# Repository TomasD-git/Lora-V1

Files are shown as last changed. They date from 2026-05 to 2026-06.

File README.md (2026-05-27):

# Lora-V1
Very complicated Lora which is mainly for 868mhz but 966mhz would work as well, has a small cell battery to keep track of time for few years, with alot of controls and a screen





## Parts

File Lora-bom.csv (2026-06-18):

Name | Purpose | Quantity | Total Cost (USD) | Link | Distributor
Cap on rotary encoder | The cap on rotary encoders that makes it easier to rotate it | 1 | 2.30 | https://www.aliexpress.com/item/10000056483250.html | Aliexpress
rotary encoder | To type messages control everything | 1 | 3.87 | https://www.aliexpress.com/item/10000056483250.html?mp=1 | Aliexpress
Screen | Actual screen all messages are shown on | 1 | 3.94 | https://www.aliexpress.com/item/1005006862867338.html | Aliexpress
PCB + Stencil | Actual pcb which all components are on + Stencil | 1 | 44.45 | https://jlcpcb.com | JLCPCB
LCSC | all components needed for this project | 1 | 54.20 | https://lcsc.com | LCSC

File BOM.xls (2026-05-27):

JLCPCB BOM Tool - BOM Matching
BOM name：BOM-JLCPCB Assembly Order.xlsx |  |  | Download Time：2026-05-25 15:41:48 |  |  |  | * Our matching results are updated in real-time, but stock and prices may change. If it's been over 24 hours, please re-match before placing your order.
PCB Assembled Qty：5 |  |  | Est. Total Price：99.2277
Your BOM |  |  |  |  | Matched Parts |  |  |  |  |  |  | Order Information
Top Designator | Bottom Designator | Comment | Footprint | JLCPCB Part # | Matches | Part # | Manufacturer | Footprint | Description | Category | Warning | JLCPCB Part # | Product link | Lib Type | Qty | Source | Total Price ($)
C1 |  | 470nF | 0402 |  | Select by System | CL05B104KO5NNNC | Samsung Electro-Mechanics | 0402 | 100nF 16V X7R ±10% 0402 Multilayer Ceramic Capacitors MLCC - SMD/SMT ROHS | Multilayer Ceramic Capacitors MLCC - SMD/SMT |  | C1525 | https://jlcpcb.com/partdetail/1877-CL05B104KO5NNNC/C1525 | Basic | 20 | 20 JLCPCB | 0.03
C2 |  | 100uF | 1210 |  | Select by System | CL32A107MQVNNNE | Samsung Electro-Mechanics | 1210 | 100uF 6.3V X5R ±20% 1210 Multilayer Ceramic Capacitors MLCC - SMD/SMT ROHS | Multilayer Ceramic Capacitors MLCC - SMD/SMT |  | C49066 | https://jlcpcb.com/partdetail/50074-CL32A107MQVNNNE/C49066 | Extended | 7 | 7 JLCPCB | 1.3447
C5,C6 |  | 100pF | 0402 |  | Select by System | 0402CG101J500NT | FH (Guangdong Fenghua Advanced Tech) | 0402 | 100pF 50V C0G ±5% 0402 Multilayer Ceramic Capacitors MLCC - SMD/SMT ROHS | Multilayer Ceramic Capacitors MLCC - SMD/SMT |  | C1546 | https://jlcpcb.com/partdetail/1898-0402CG101J500NT/C1546 | Basic | 20 | 20 JLCPCB | 0.024
C10,C13,C4,C9 |  | 10pF | 0402 |  | Select by System | GRM1555C1H100GA01D | Murata Electronics | 0402 | 10pF 50V C0G ±2% 0402 Multilayer Ceramic Capacitors MLCC - SMD/SMT ROHS | Multilayer Ceramic Capacitors MLCC - SMD/SMT |  | C76945 | https://jlcpcb.com/partdetail/MurataElectronics-GRM1555C1H100GA01D/C76945 | Extended | 30 | 30 JLCPCB | 0.195
C11,C12,C7,C8 |  | 8.2pF | 0402 |  | Select by System | 0402CG8R2C500NT | FH (Guangdong Fenghua Advanced Tech) | 0402 | 50V 8.2pF C0G 0402 Multilayer Ceramic Capacitors MLCC - SMD/SMT ROHS | Multilayer Ceramic Capacitors MLCC - SMD/SMT |  | C1579 | https://jlcpcb.com/partdetail/1931-0402CG8R2C500NT/C1579 | Extended | 30 | 30 JLCPCB | 0.039
C14,C15 |  | 1nF | 0402 |  | Select by System | 0402CG102J500NT | FH (Guangdong Fenghua Advanced Tech) | 0402 | 1nF 50V C0G ±5% 0402 Multilayer Ceramic Capacitors MLCC - SMD/SMT ROHS | Multilayer Ceramic Capacitors MLCC - SMD/SMT |  | C53547 | https://jlcpcb.com/partdetail/54563-0402CG102J500NT/C53547 | Extended | 20 | 20 JLCPCB | 0.074
C16,C17,C18 |  | 33pF | 0402 |  | Select by System | 0402CG330J500NT | FH (Guangdong Fenghua Advanced Tech) | 0402 | 33pF 50V C0G ±5% 0402 Multilayer Ceramic Capacitors MLCC - SMD/SMT ROHS | Multilayer Ceramic Capacitors MLCC - SMD/SMT |  | C1562 | https://jlcpcb.com/partdetail/1914-0402CG330J500NT/C1562 | Basic | 25 | 25 JLCPCB | 0.0325
C19,C21,C3 |  | 1uF | 0402 |  | Select by System | CL05A105KA5NQNC | Samsung Electro-Mechanics | 0402 | 1uF 25V X5R ±10% 0402 Multilayer Ceramic Capacitors MLCC - SMD/SMT ROHS | Multilayer Ceramic Capacitors MLCC - SMD/SMT |  | C52923 | https://jlcpcb.com/partdetail/53938-CL05A105KA5NQNC/C52923 | Basic | 25 | 25 JLCPCB | 0.1
C20,C22,C23,C38 |  | 100nF | 0402 |  | Select by System | CL05B104KB54PNC | Samsung Electro-Mechanics | 0402 | 100nF 50V X7R ±10% 0402 Multilayer Ceramic Capacitors MLCC - SMD/SMT ROHS | Multilayer Ceramic Capacitors MLCC - SMD/SMT |  | C307331 | https://jlcpcb.com/partdetail/291005-CL05B104KB54PNC/C307331 | Basic | 30 | 30 JLCPCB | 0.138
C24 |  | 47nF | 0402 |  | Select by System | 0402B473K500NT | FH (Guangdong Fenghua Advanced Tech) | 0402 | 47nF 50V X7R ±10% 0402 Multilayer Ceramic Capacitors MLCC - SMD/SMT ROHS | Multilayer Ceramic Capacitors MLCC - SMD/SMT |  | C82219 | https://jlcpcb.com/partdetail/83376-0402B473K500NT/C82219 | Extended | 20 | 20 JLCPCB | 0.04
C25 |  | 4.7uF | 0603 |  | Select by System | CL10A475KO8NNNC | Samsung Electro-Mechanics | 0603 | 16V 4.7uF X5R ±10% 0603 Multilayer Ceramic Capacitors MLCC - SMD/SMT ROHS | Multilayer Ceramic Capacitors MLCC - SMD/SMT |  | C19666 | https://jlcpcb.com/partdetail/20375-CL10A475KO8NNNC/C19666 | Basic | 20 | 20 JLCPCB | 0.22
C26,C28,C29,C30,C31,C33 |  | 10uF | 0603 |  | Select by System | CL10A106KP8NNNC | Samsung Electro-Mechanics | 0603 | 10V 10uF X5R ±10% 0603 Multilayer Ceramic Capacitors MLCC - SMD/SMT ROHS | Multilayer Ceramic Capacitors MLCC - SMD/SMT |  | C19702 | https://jlcpcb.com/partdetail/20411-CL10A106KP8NNNC/C19702 | Basic | 40 | 40 JLCPCB | 0.428
C27,C32 |  | 22uF | 0805 |  | Select by System | CL21A226MAQNNNE | Samsung Electro-Mechanics | 0805 | 22uF 25V X5R ±20% 0805 Multilayer Ceramic Capacitors MLCC - SMD/SMT ROHS | Multilayer Ceramic Capacitors MLCC - SMD/SMT |  | C45783 | https://jlcpcb.com/partdetail/46786-CL21A226MAQNNNE/C45783 | Basic | 20 | 20 JLCPCB | 0.692
C34,C35,C36,C37 |  | 4.7nF | 0402 |  | Select by System | CC0402JRX7R9BB472 | YAGEO | 0402 | 4.7nF 50V X7R ±5% 0402 Multilayer Ceramic Capacitors MLCC - SMD/SMT ROHS | Multilayer Ceramic Capacitors MLCC - SMD/SMT |  | C281757 | https://jlcpcb.com/partdetail/YAGEO-CC0402JRX7R9BB472/C281757 | Extended | 30 | 30 JLCPCB | 0.054
CN1 |  | PH2.0 | 插件,P=2mm |  | Select by System | B2B-PH-K-S(LF)(SN) | JST | 插件,P=2mm | -25℃~+85℃ 1 100V 1x2P 2 2A 2P 2mm 4.5mm 5.9mm 6mm Brass K Pin PA66 PH Through Hole Tin UL94V-0 White 插件,P=2mm Wire To Board Connector ROHS | Wire To Board Connector |  | C131337 | https://jlcpcb.com/partdetail/JST-B2B_PH_K_S_LF_SN/C131337 | Extended | 6 | 6 JLCPCB | 0.1998
D1 |  | LED | 0603 |  | Select by System | XL-1608SURC-06 | XINGLIGHT | 0603 | -40℃~+85℃ 120° 2.3V 20mA 225mcd 50mW 620nm~630nm 625nm Discrete Diode Red Top-mount Water Clear 0603 LED Indication - Discrete ROHS | LED Indication - Discrete |  | C965799 | https://jlcpcb.com/partdetail/XINGLIGHT-XL_1608SURC06/C965799 | Extended | 20 | 20 JLCPCB | 0.076
J1 |  | Conn_Coaxial | SMD,D6.3xL5.4mm |  | Select by Customer | U.FL-R-SMT-1(80) | HRS(Hirose) | SMD | -40℃~+90℃ 1 1.25mm 2mm 50Ω 6GHz Board Side IPEX Male Pin SMD Coaxial Connectors (RF) ROHS | Coaxial Connectors (RF) |  | C88374 | https://jlcpcb.com/partdetail/HRS_Hirose-U_FL_R_SMT_1_80/C88374 | Extended | 7 | 7 JLCPCB | 0.7665
L1 |  | 15uH | 0805 |  | Select by System | MLZ2012M150WT000 | TDK | 0805 | 120mA 15uH 250mA 2MHz 950mΩ Multilayer inductor ±20% 0805 Inductors (SMD) ROHS | Inductors (SMD) |  | C383402 | https://jlcpcb.com/partdetail/TDK-MLZ2012M150WT000/C383402 | Extended | 9 | 9 JLCPCB | 0.5706
L2,L3,L4,L5,L6 |  | 8.2nH | 0402 |  | Select by System | LQW15AN8N2G00D | Murata Electronics | 0402 | 140mΩ 540mA 8.2nH Unshielded Inductor ±2% 0402 Power Inductors ROHS | Power Inductors |  | C84404 | https://jlcpcb.com/partdetail/MurataElectronics-LQW15AN8N2G00D/C84404 | Extended | 29 | 29 JLCPCB | 1.1716
L7 |  | 10nH | 0402 |  | Select by System | LQW15AN10NG00D | Murata Electronics | 0402 | 10nH 170mΩ 500mA Unshielded Inductor ±2% 0402 Power Inductors ROHS | Power Inductors |  | C90642 | https://jlcpcb.com/partdetail/MurataElectronics-LQW15AN10NG00D/C90642 | Extended | 9 | 9 JLCPCB | 0.3258
L8 |  | 2.2uH | 1008 |  | Select by System | LQM2HPN2R2MG0L | Murata Electronics | 1008 | 1.3A 100mΩ 2.2uH 40MHz ±20% 1008 Inductors (SMD) ROHS | Inductors (SMD) |  | C86092 | https://jlcpcb.com/partdetail/MurataElectronics-LQM2HPN2R2MG0L/C86092 | Extended | 7 | 7 JLCPCB | 0.6349
L9 |  | 1.5uH | 1210 |  | Select by System | NLV32T-1R5J-PF | TDK | 1210 | 1.5uH 370mA 850mΩ Magnetic Shielded Inductor ±5% 1210 Power Inductors ROHS | Power Inductors |  | C76837 | https://jlcpcb.com/partdetail/TDK-NLV32T_1R5JPF/C76837 | Extended | 9 | 9 JLCPCB | 0.4068
Q1,Q4 |  | 2N3904 | TO-92 |  | Select by System | 2N3904 | JSMSEMI | TO-92 | -55℃~+150℃ 1 NPN 200mA 300 300MHz 300mV 40V 50nA 625mW 6V NPN TO-92 Bipolar (BJT) ROHS | Bipolar (BJT) |  | C2874602 | https://jlcpcb.com/partdetail/JSMSEMI-2N3904/C2874602 | Extended | 12 | 12 JLCPCB | 0.144
Q2,Q3 |  | AO3401A | SOT-23 |  | Select by System | AO3401A | Alpha & Omega Semicon | SOT-23 | 1 P-Channel 14nC@10V 30V 47mΩ@10V、60mΩ@4.5V、85mΩ@2.5V 4A 55pF 645pF 80pF 900mV SOT-23 MOSFETs ROHS | MOSFETs |  | C15127 | https://jlcpcb.com/partdetail/Alpha_OmegaSemicon-AO3401A/C15127 | Basic | 14 | 14 JLCPCB | 0.8218
R1,R17 |  | 100K | 0402 |  | Select by System | FRC0402F1003TS | FOJAN | 0402 | -55℃~+155℃ 100kΩ 50V 62.5mW Thick Film Resistor ±1% ±100ppm/℃ 0402 Chip Resistor - Surface Mount ROHS | Chip Resistor - Surface Mount |  | C2906859 | https://jlcpcb.com/partdetail/FOJAN-FRC0402F1003TS/C2906859 | Extended | 20 | 20 JLCPCB | 0.012
R3,R4 |  | 22Ω | 0402 |  | Select by System | RC0402FR-0722RL | YAGEO | 0402 | -55℃~+155℃ 22Ω 50V 62.5mW Thick Film Resistor ±1% ±100ppm/℃ 0402 Chip Resistor - Surface Mount ROHS | Chip Resistor - Surface Mount |  | C114765 | https://jlcpcb.com/partdetail/YAGEO-RC0402FR0722RL/C114765 | Extended | 20 | 20 JLCPCB | 0.018
R6 |  | 15K | 0402 |  | Select by System | 0402WGF1502TCE | UNI-ROYAL(Uniroyal Elec) | 0402 | -55℃~+155℃ 15kΩ 50V 62.5mW Thick Film Resistor ±1% ±100ppm/℃ 0402 Chip Resistor - Surface Mount ROHS | Chip Resistor - Surface Mount |  | C25756 | https://jlcpcb.com/partdetail/26499-0402WGF1502TCE/C25756 | Basic | 20 | 20 JLCPCB | 0.016
R9 |  | 31.6K | 0402 |  | Select by System | RC0402FR-0731K6L | YAGEO | 0402 | -55℃~+155℃ 31.6kΩ 50V 62.5mW Thick Film Resistor ±1% ±100ppm/℃ 0402 Chip Resistor - Surface Mount ROHS | Chip Resistor - Surface Mount |  | C276265 | https://jlcpcb.com/partdetail/YAGEO-RC0402FR0731K6L/C276265 | Extended | 20 | 20 JLCPCB | 0.018
R10,R22,R24 |  | 1K | 0402 |  | Select by System | RC0402FR-071KL | YAGEO | 0402 | -55℃~+155℃ 1kΩ 50V 62.5mW Thick Film Resistor ±1% ±100ppm/℃ 0402 Chip Resistor - Surface Mount ROHS | Chip Resistor - Surface Mount |  | C106235 | https://jlcpcb.com/partdetail/YAGEO-RC0402FR071KL/C106235 | Extended | 25 | 25 JLCPCB | 0.0225
R11,R15,R18,R19,R2,R20,R21,R23,R25,R26,R27,R5,R7,R8 |  | 10K | 0402 |  | Select by System | FRC0402F1002TS | FOJAN | 0402 | -55℃~+155℃ 10kΩ 50V 62.5mW Thick Film Resistor ±1% ±100ppm/℃ 0402 Chip Resistor - Surface Mount ROHS | Chip Resistor - Surface Mount |  | C2906861 | https://jlcpcb.com/partdetail/FOJAN-FRC0402F1002TS/C2906861 | Extended | 80 | 80 JLCPCB | 0.048
R12,R13 |  | 5.1K | 0402 |  | Select by System | FRC0402F5101TS | FOJAN | 0402 | -55℃~+155℃ 5.1kΩ 50V 62.5mW Thick Film Resistor ±1% ±100ppm/℃ 0402 Chip Resistor - Surface Mount ROHS | Chip Resistor - Surface Mount |  | C2906874 | https://jlcpcb.com/partdetail/FOJAN-FRC0402F5101TS/C2906874 | Extended | 20 | 20 JLCPCB | 0.014
R14 |  | 178K | 0402 |  | Select by System | FRC0402F1783TS | FOJAN | 0402 | -55℃~+155℃ 178kΩ 50V 62.5mW Thick Film Resistor ±1% ±100ppm/℃ 0402 Chip Resistor - Surface Mount ROHS | Chip Resistor - Surface Mount |  | C3013156 | https://jlcpcb.com/partdetail/FOJAN-FRC0402F1783TS/C3013156 | Extended | 20 | 20 JLCPCB | 0.012
R16 |  | 267Ω | 0402 |  | Select by System | AC0402FR-07267RL | YAGEO | 0402 | -55℃~+155℃ 267Ω 50V 62.5mW Thick Film Resistor ±1% ±100ppm/℃ 0402 Chip Resistor - Surface Mount ROHS | Chip Resistor - Surface Mount |  | C226381 | https://jlcpcb.com/partdetail/YAGEO-AC0402FR07267RL/C226381 | Extended | 20 | 20 JLCPCB | 0.028
SW1 |  | RST | SMD-4P,6x6mm |  | Unconfirmed | PTS645SM43SMTR92LFS | C&K | SMD-4P,6x6mm | -20℃~+85℃ 1.6N 12V 4.3mm 50mA 6mm 6mm Gull Wing Round Button SPST Surface Mount,Vertical SMD-4P,6x6mm Tactile Switches ROHS | Tactile Switches | 1.Multiple lines in the BOM have been matched to the same part. Please check if the matching is correct. ; | C221880 | https://jlcpcb.com/partdetail/CK-PTS645SM43SMTR92LFS/C221880 | Extended | 15 | 15 JLCPCB | 4.0695
SW2 |  | BOOT | SMD-4P,6x6mm |  | Unconfirmed | PTS645SM43SMTR92LFS | C&K | SMD-4P,6x6mm | -20℃~+85℃ 1.6N 12V 4.3mm 50mA 6mm 6mm Gull Wing Round Button SPST Surface Mount,Vertical SMD-4P,6x6mm Tactile Switches ROHS | Tactile Switches | 1.Multiple lines in the BOM have been matched to the same part. Please check if the matching is correct. ; | C221880 | https://jlcpcb.com/partdetail/CK-PTS645SM43SMTR92LFS/C221880 | Extended | 15 | 15 JLCPCB | 4.0695
SW3 |  | PWR_RST | SMD-4P,6x6mm |  | Unconfirmed | PTS645SM43SMTR92LFS | C&K | SMD-4P,6x6mm | -20℃~+85℃ 1.6N 12V 4.3mm 50mA 6mm 6mm Gull Wing Round Button SPST Surface Mount,Vertical SMD-4P,6x6mm Tactile Switches ROHS | Tactile Switches | 1.Multiple lines in the BOM have been matched to the same part. Please check if the matching is correct. ; | C221880 | https://jlcpcb.com/partdetail/CK-PTS645SM43SMTR92LFS/C221880 | Extended | 15 | 15 JLCPCB | 4.0695
U1 |  | SX1262IMLTRT | QFN-24-EP(4x4) |  | Select by System | SX1262IMLTRT | SEMTECH | QFN-24-EP(4x4) | -148dBm -40℃~+85℃ 1.8V~3.7V 150MHz~960MHz 22dBm 300Kbps 32mA 4.2mA ISM SPI transceiver QFN-24-EP(4x4) RF Transceiver ICs ROHS | RF Transceiver ICs |  | C191341 | https://jlcpcb.com/partdetail/SEMTECH-SX1262IMLTRT/C191341 | Extended | 5 | 5 JLCPCB | 16.086
U2 |  | PE4259 | SC-70-6 |  | Select by System | PE4259-63 | pSemi | SC-70-6 | -40℃~+85℃ 0.35dB 1.8V~3.3V 10MHz~3GHz 30dB 33.5dBm Integrated control logic SPDT SC-70-6 RF Switches ROHS | RF Switches |  | C470892 | https://jlcpcb.com/partdetail/pSemi-PE425963/C470892 | Extended | 5 | 5 JLCPCB | 3.134
U3 |  | ESP32-S3-MINI-1U | VFQFN-56-EP |  | Select by System | ESP32-S3-MINI-1U-N8 | Espressif Systems | VFQFN-56-EP | -40℃~+105℃ -98.4dBm 1.8V~3.6V、3V~3.6V 2.4GHz 21dBm 340mA 88mA Bluetooth5.0 ESP32-S3 UART、SDIO、SPI、I2C、I2S、JTAG、USB VFQFN-56-EP WiFi Modules ROHS | WiFi Modules |  | C2980299 | https://jlcpcb.com/partdetail/3401551-ESP32_S3_MINI_1UN8/C2980299 | Extended | 5 | 5 JLCPCB | 24.9645
U4 |  | BQ25895RTW | QFN-24-EP(4x4) |  | Select by System | BQ25895RTWR | Texas Instruments | QFN-24-EP(4x4) | -40℃~+85℃ 1 12uA 3.9V~14V 4.608V 5A Charging IC I2C Lithium Battery Support Support QFN-24-EP(4x4) Battery Management ROHS | Battery Management |  | C80200 | https://jlcpcb.com/partdetail/TexasInstruments-BQ25895RTWR/C80200 | Extended | 5 | 5 JLCPCB | 11.0965
U5 |  | TPS631000DRLR | SOT-583 |  | Select by System | TPS631000DRLR | Texas Instruments | SOT-583 | -40℃~+125℃ 1.2V~5.3V 1.6V~5.5V 2.2MHz 2A 8uA Adjustable Buck-Boost Buck-Boost Built-in SOT-583 DC-DC Converters ROHS | DC-DC Converters |  | C5219190 | https://jlcpcb.com/partdetail/TexasInstruments-TPS631000DRLR/C5219190 | Extended | 5 | 5 JLCPCB | 2.3625
U6 |  | W25Q128JVPIMTR | WSON-8-EP(5x6) |  | Select by System | W25Q128JVPIM TR | Winbond Elec | WSON-8-EP(5x6) | -40℃~+85℃ 100,000 cycles 10uA 128Mbit 133MHz 2.7V~3.6V 20 Years 3ms SPI WSON-8-EP(5x6) NOR FLASH ROHS | NOR FLASH |  | C2441427 | https://jlcpcb.com/partdetail/WinbondElec-W25Q128JVPIMTR/C2441427 | Extended | 5 | 5 JLCPCB | 14.254
U7 |  | XDCR-1220-006 | SMD |  | Select by System | XDCR-1220-006 | Lian Xin Technology | SMD | -40℃~+85℃ Battery base CR1220 Gold SMD Button And Strip Battery Connector ROHS | Button And Strip Battery Connector |  | C7498147 | https://jlcpcb.com/partdetail/Lian_XinTechnology-XDCR_1220006/C7498147 | Extended | 5 | 5 JLCPCB | 0.724
U8 |  | PCF85063ATL/1,118 | DFN-10-EP(2.6x2.6) |  | Select by System | PCF85063ATL/1,118 | NXP Semicon | DFN-10-EP(2.6x2.6) | -40℃~+85℃ 0.22uA 220nA 900mV~5.5V Built-in I2C InsideSRAM/NVRAM、Programmable clock output、Alarm function、Periodic interrupt output、Countdown timer Yes DFN-10-EP(2.6x2.6) Real Time Clocks ROHS | Real Time Clocks |  | C404360 | https://jlcpcb.com/partdetail/NXPSemicon-PCF85063ATL_1118/C404360 | Extended | 5 | 5 JLCPCB | 3.7445
USB1 |  | USB-TYPE-C-018 | SMD |  | Select by System | USB-TYPE-C-018 | DEALON | SMD | -25℃~+85℃ 1 10000 times 16P 3A 5V 7.35mm Female Surface Mount, Right Angle Type-C SMD USB Connectors ROHS | USB Connectors |  | C2927038 | https://jlcpcb.com/partdetail/DEALON-USB_TYPE_C018/C2927038 | Extended | 5 | 5 JLCPCB | 0.2805
Y1 |  | 32MHz | SMD3225-4P |  | Select by System | X322532MMB4SI | YXC Crystal Oscillators | SMD3225-4P | -40℃~+85℃ 10pF 32MHz Crystal Oscillator ±10ppm ±20ppm SMD3225-4P Crystals ROHS | Crystals |  | C113671 | https://jlcpcb.com/partdetail/114906-X322532MMB4SI/C113671 | Extended | 9 | 9 JLCPCB | 0.7452
Y3 |  | 32.768kHz | SMD3215-2P |  | Select by System | Q13FC13500002 | Seiko Epson | SMD3215-2P | -40℃~+85℃ 32.768kHz 70kΩ 7pF Crystal Oscillator ±20ppm SMD3215-2P Crystals ROHS | Crystals |  | C48615 | https://jlcpcb.com/partdetail/SeikoEpson-Q13FC13500002/C48615 | Extended | 5 | 5 JLCPCB | 0.91

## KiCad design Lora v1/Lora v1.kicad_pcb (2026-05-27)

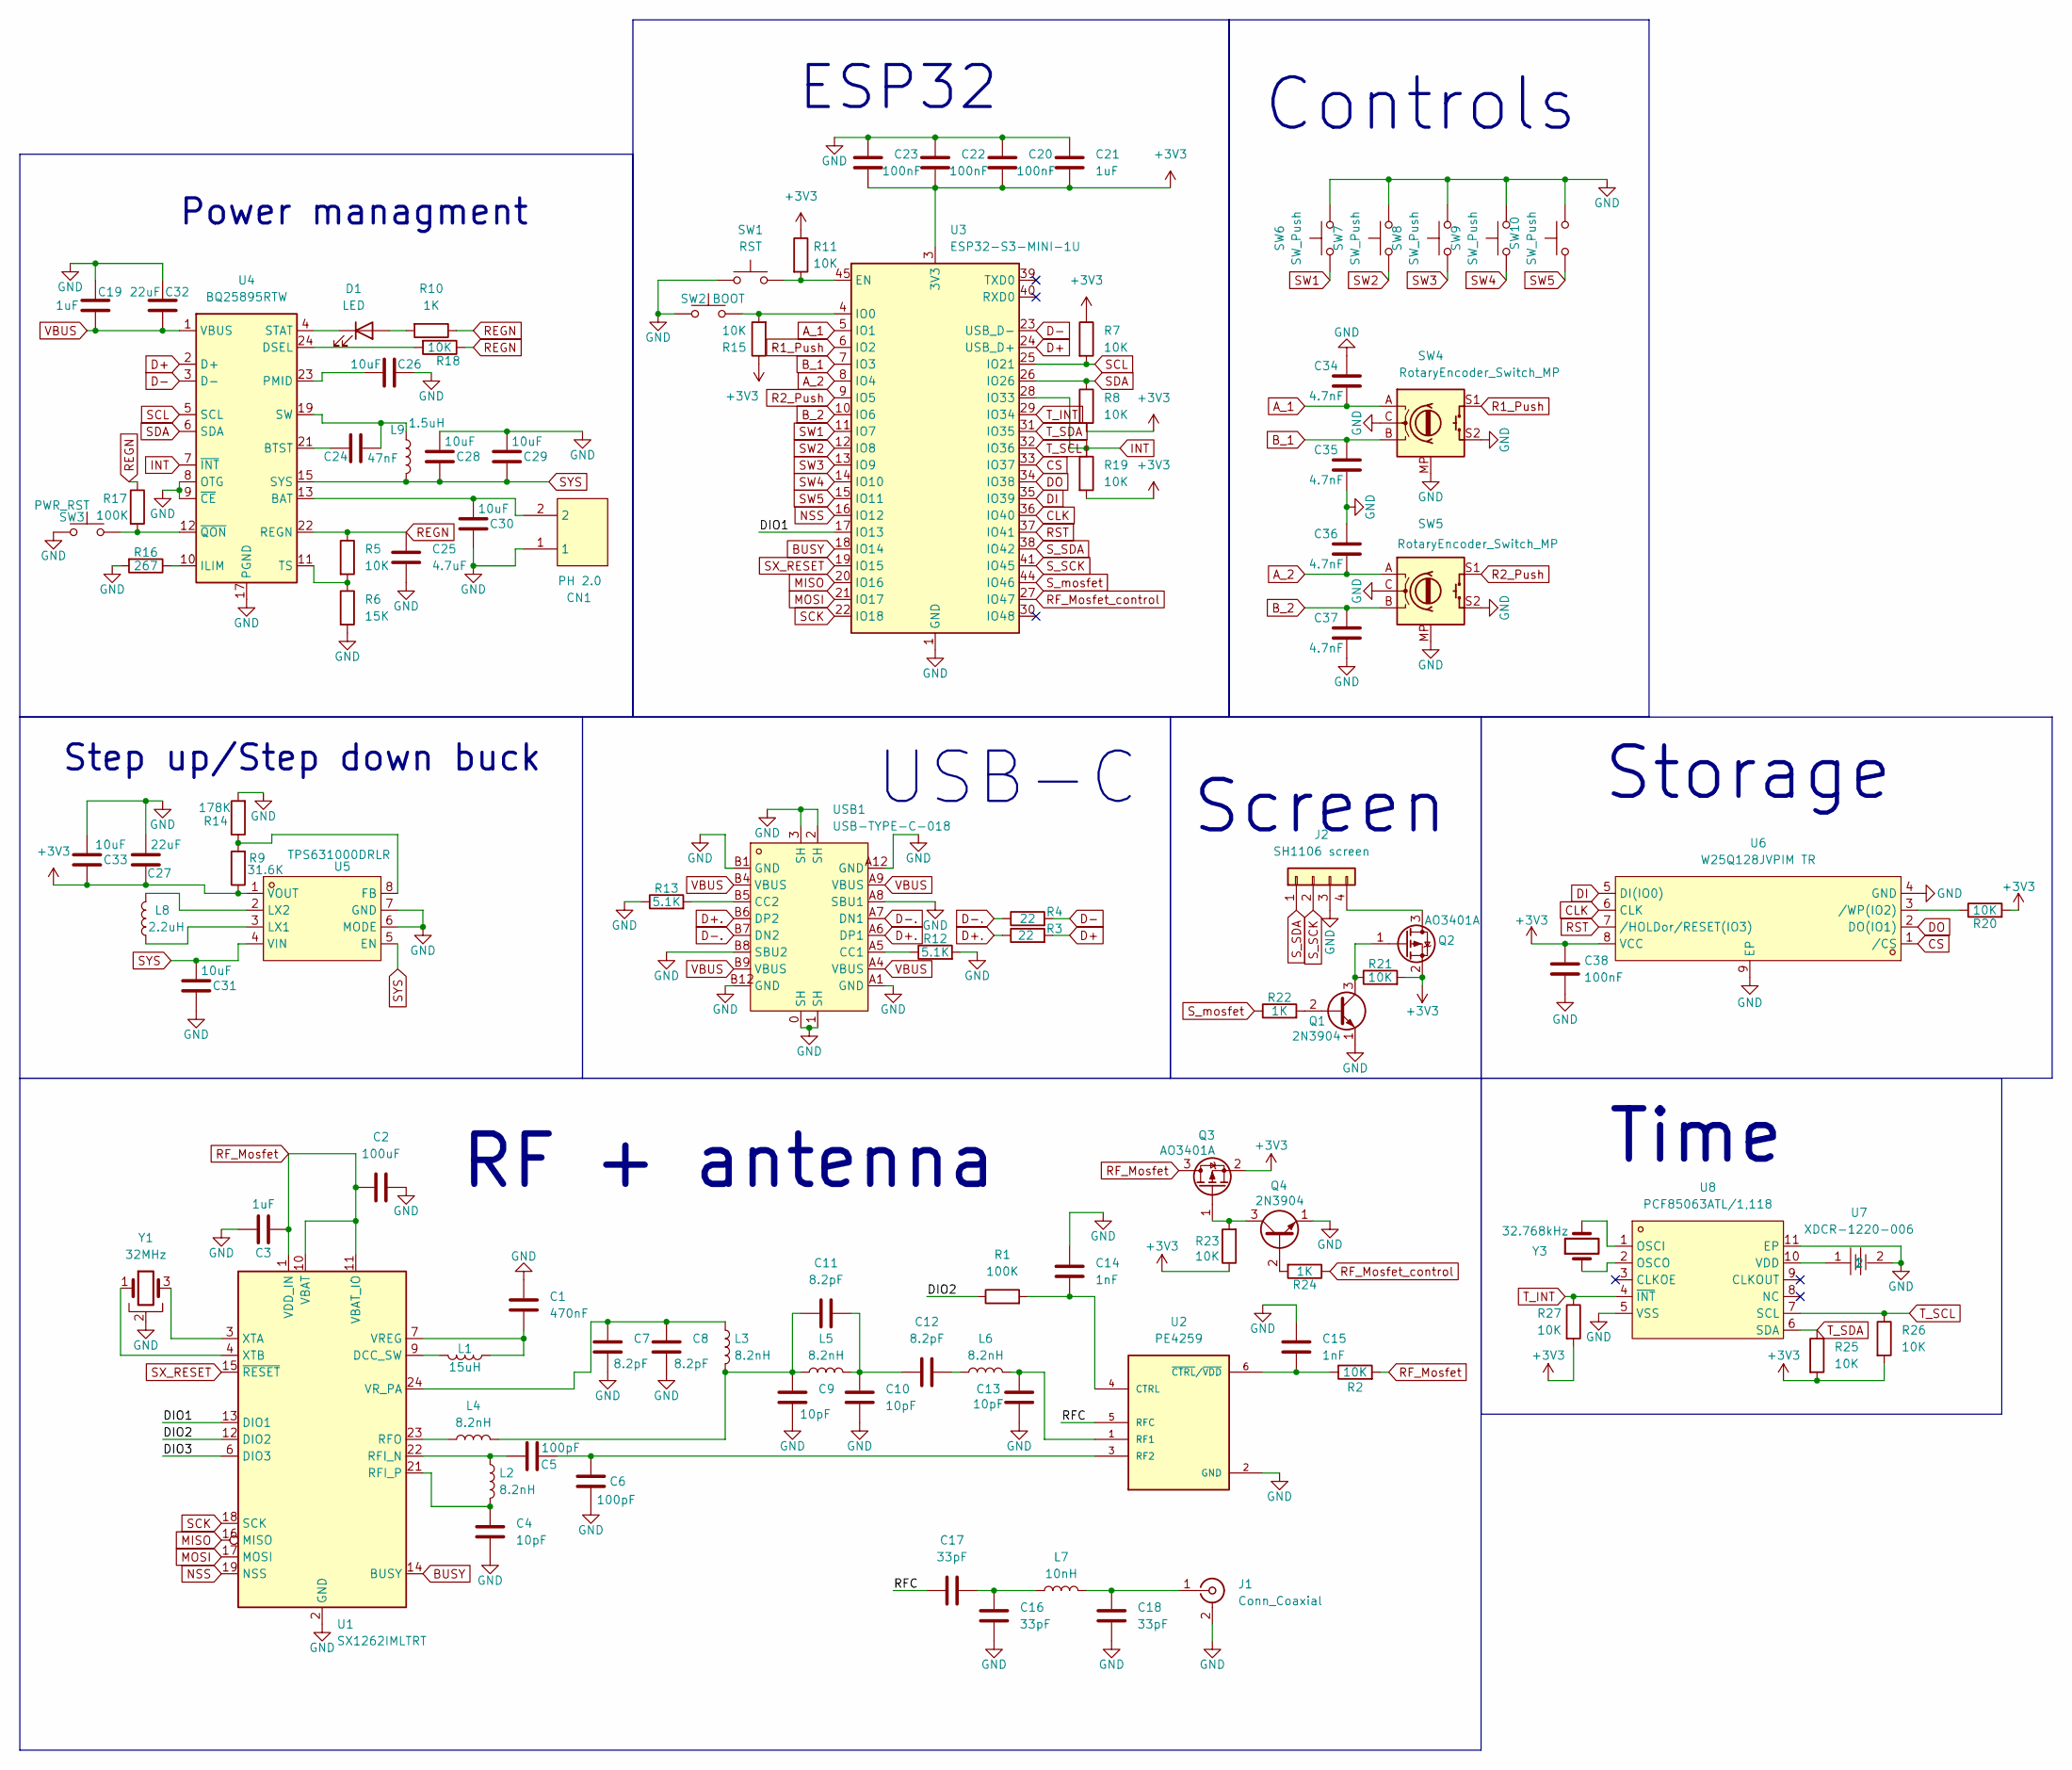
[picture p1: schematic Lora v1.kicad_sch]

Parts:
C1: 470nF; C_0402_1005Metric
C2: 100uF; C_1210_3225Metric
C3, C19, C21: 1uF; C_0402_1005Metric
C4, C9, C10, C13: 10pF; C_0402_1005Metric
C5, C6: 100pF; C_0402_1005Metric
C7, C8, C11, C12: 8.2pF; C_0402_1005Metric
C14, C15: 1nF; C_0402_1005Metric
C16, C17, C18: 33pF; C_0402_1005Metric
C20, C22, C23, C38: 100nF; C_0402_1005Metric
C24: 47nF; C_0402_1005Metric
C25: 4.7uF; C_0603_1608Metric
C26, C28, C29, C30, C31, C33: 10uF; C_0603_1608Metric
C27, C32: 22uF; C_0805_2012Metric
C34, C35, C36, C37: 4.7nF; C_0402_1005Metric
CN1: PH 2.0; CONN-TH_B2B-PH-K-S; MPN B2B-PH-K-S(LF)(SN); LCSC Part C131337
D1: LED; LED_0603_1608Metric
J1: Conn_Coaxial; U.FL_Hirose_U.FL-R-SMT-1_Vertical
J2: SH1106 screen; PinHeader_1x04_P2.54mm_Vertical
L1: 15uH; L_0805_2012Metric
L2, L3, L4, L5, L6: 8.2nH; L_0402_1005Metric
L7: 10nH; L_0402_1005Metric
L8: 2.2uH; L_1008_2520Metric
L9: 1.5uH; L_1210_3225Metric
Q1, Q4: 2N3904; TO-92_Inline
Q2, Q3: AO3401A; SOT-23
R1, R17: 100K; R_0402_1005Metric
R2, R5, R7, R8, R11, R15, R18, R19, R20, R21, R23, R25, R26, R27: 10K; R_0402_1005Metric
R3, R4: 22; R_0402_1005Metric
R6: 15K; R_0402_1005Metric
R9: 31.6K; R_0402_1005Metric
R10, R22, R24: 1K; R_0402_1005Metric
R12, R13: 5.1K; R_0402_1005Metric
R14: 178K; R_0402_1005Metric
R16: 267; R_0402_1005Metric
SW1: RST; SW_SPST_PTS645Sx43SMTR92
SW2: BOOT; SW_SPST_PTS645Sx43SMTR92
SW3: PWR_RST; SW_SPST_PTS645Sx43SMTR92
SW4, SW5: RotaryEncoder_Switch_MP; RotaryEncoder_Alps_EC11E-Switch_Vertical_H20mm
SW6, SW7, SW8, SW9, SW10: SW_Push; SW_Cherry_MX_PCB_1.00u
U1: SX1262IMLTRT; QFN-24-1EP_4x4mm_P0.5mm_EP2.6x2.6mm
U2: PE4259; SOT65P215X110-6N
U3: ESP32-S3-MINI-1U; ESP32-S2-MINI-1U
U4: BQ25895RTW; Texas_RTW_WQFN-24-1EP_4x4mm_P0.5mm_EP2.7x2.7mm_ThermalVias
U5: TPS631000DRLR; SOT-583-8_L2.1-W1.2-P0.50-LS1.6-BL; MPN TPS631000DRLR; LCSC Part C5219190
U6: W25Q128JVPIM TR; WSON-8_L6.0-W5.0-P1.27-BL-EP; MPN W25Q128JVPIM TR; LCSC Part C2441427
U7: XDCR-1220-006; BAT-SMD_CR1220-2ZX; MPN XDCR-1220-006; LCSC Part C7498147
U8: PCF85063ATL/1,118; DFN-10_L2.6-W2.6-P0.50-BL-EP; MPN PCF85063ATL/1,118; LCSC Part C404360
USB1: USB-TYPE-C-018; USB-C_SMD-TYPE-C-31-M-12; MPN USB-TYPE-C-018; LCSC Part C2927038
Y1: 32MHz; Crystal_SMD_3225-4Pin_3.2x2.5mm
Y3: 32.768kHz; Crystal_SMD_3215-2Pin_3.2x1.5mm

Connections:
+3V3: C20.2, C21.2, C22.2, C23.2, C27.1, C33.1, C38.1, Q2.2 (S), Q3.2 (S), R7.1, R8.2, R9.1, R11.1, R15.1, R19.2, R20.2, R21.2, R23.1, R25.2, R26.2, R27.2, U3.3 (3V3), U5.1 (VOUT), U6.8 (VCC)
/DIO1: U1.13 (DIO1), U3.17 (IO13)
/DIO2: R1.1, U1.12 (DIO2)
/DIO3: U1.6 (DIO3)
/RFC: C17.1, U2.5 (RFC)
A_1: C34.1, SW4.A, U3.5 (IO1)
A_2: C36.1, SW5.A, U3.8 (IO4)
BUSY: U1.14 (BUSY), U3.18 (IO14)
B_1: C35.2, SW4.B, U3.7 (IO3)
B_2: C37.2, SW5.B, U3.10 (IO6)
CLK: U3.36 (IO40), U6.6 (CLK)
CS: U3.33 (IO37), U6.1 (/CS)
D+: R3.2, U3.24 (USB_D+), U4.2 (D+)
D+.: R3.1, USB1.A6 (DP1), USB1.B6 (DP2)
D-: R4.2, U3.23 (USB_D-), U4.3 (D-)
D-.: R4.1, USB1.A7 (DN1), USB1.B7 (DN2)
DI: U3.35 (IO39), U6.5 (DI(IO0))
DO: U3.34 (IO38), U6.2 (DO(IO1))
GND: C1.1, C2.2, C3.1, C4.2, C6.1, C7.2, C8.2, C9.2, C10.2, C13.2, C14.1, C15.1, C16.2, C18.2, C19.1, C20.1, C21.1, C22.1, C23.1, C25.2, C26.2, C27.2, C28.2, C29.2, C30.1, C31.1, C32.1, C33.2, C34.2, C35.1, C36.2, C37.1, C38.2, CN1.1, J1.2 (Ext), J2.3, Q1.1 (E), Q4.1 (E), R6.2, R12.2, R13.1, R14.2, R16.2, SW1.1, SW2.1, SW3.1, SW4.C, SW4.MP, SW4.S2, SW5.C, SW5.MP, SW5.S2, SW6.2, SW7.2, SW8.2, SW9.2, SW10.2, U1.2 (GND), U1.5 (GND), U1.8 (GND), U1.20 (GND), U1.25 (GND), U2.2 (GND), U3.1 (GND), U3.2 (GND), U3.42 (GND), U3.43 (GND), U3.46 (GND), U3.47 (GND), U3.48 (GND), U3.49 (GND), U3.50 (GND), U3.51 (GND), U3.52 (GND), U3.53 (GND), U3.54 (GND), U3.55 (GND), U3.56 (GND), U3.57 (GND), U3.58 (GND), U3.59 (GND), U3.60 (GND), U3.61 (GND), U3.62 (GND), U3.63 (GND), U3.64 (GND), U3.65 (GND), U4.8 (OTG), U4.9 (~CE), U4.17 (PGND), U4.18 (PGND), U4.25 (PGND), U5.6 (MODE), U5.7 (GND), U6.4 (GND), U6.9 (EP), U7.2, U8.5 (VSS), U8.11 (EP), USB1.0 (SH), USB1.1 (SH), USB1.2 (SH), USB1.3 (SH), USB1.A1 (GND), USB1.A8 (SBU1), USB1.A12 (GND), USB1.B1 (GND), USB1.B8 (SBU2), USB1.B12 (GND), Y1.2
INT: R19.1, U3.28 (IO33), U4.7 (~INT)
MISO: U1.16 (MISO), U3.20 (IO16)
MOSI: U1.17 (MOSI), U3.21 (IO17)
NSS: U1.19 (NSS), U3.16 (IO12)
unnamed: C10.1, C11.2, C12.1, L5.2
unnamed: C9.1, C11.1, L3.2, L4.2, L5.1
unnamed: C12.2, L6.1
unnamed: C16.1, C17.2, L7.1
unnamed: C24.1, L9.1, U4.19 (SW), U4.20 (SW)
unnamed: C30.2, CN1.2, U4.13 (BAT), U4.14 (BAT)
unnamed: D1.2 (A), R10.2
unnamed: D1.1 (K), U4.4 (STAT)
unnamed: C18.1, J1.1 (In), L7.2
unnamed: J2.4, Q2.3 (D)
unnamed: Q1.2 (B), R22.2
unnamed: Q1.3 (C), Q2.1 (G), R21.1
unnamed: Q3.1 (G), Q4.3 (C), R23.2
unnamed: Q4.2 (B), R24.2
unnamed: L1.2, U1.9 (DCC_SW)
unnamed: C5.1, L2.1, U1.22 (RFI_N)
unnamed: C4.1, L2.2, U1.21 (RFI_P)
unnamed: L4.1, U1.23 (RFO)
unnamed: C1.2, L1.1, U1.7 (VREG)
unnamed: C7.1, C8.1, L3.1, U1.24 (VR_PA)
unnamed: U1.3 (XTA), Y1.3
unnamed: U1.4 (XTB), Y1.1
unnamed: C14.2, R1.2, U2.4 (CTRL)
unnamed: C13.1, L6.2, U2.1 (RF1)
unnamed: C5.2, C6.2, U2.3 (RF2)
unnamed: C15.2, R2.1, U2.6 (~CTRL/~VDD)
unnamed: R11.2, SW1.2, U3.45 (EN)
unnamed: R15.2, SW2.2, U3.4 (IO0)
unnamed: C24.2, U4.21 (BTST)
unnamed: R18.2, U4.24 (DSEL)
unnamed: R16.1, U4.10 (ILIM)
unnamed: C26.1, U4.23 (PMID)
unnamed: R5.2, R6.1, U4.11 (TS)
unnamed: R17.2, SW3.2, U4.12 (~QON)
unnamed: R9.2, R14.1, U5.8 (FB)
unnamed: L8.1, U5.3 (LX1)
unnamed: L8.2, U5.2 (LX2)
unnamed: R20.1, U6.3 (/WP(IO2))
unnamed: U8.1 (OSCI), Y3.2
unnamed: U8.2 (OSCO), Y3.1
unnamed: U7.1, U8.10 (VDD)
unnamed: R12.1, USB1.A5 (CC1)
unnamed: R13.2, USB1.B5 (CC2)
R1_Push: SW4.S1, U3.6 (IO2)
R2_Push: SW5.S1, U3.9 (IO5)
REGN: C25.1, R5.1, R10.1, R17.1, R18.1, U4.22 (REGN)
RF_Mosfet: C2.1, C3.2, Q3.3 (D), R2.2, U1.1 (VDD_IN), U1.10 (VBAT), U1.11 (VBAT_IO)
RF_Mosfet_control: R24.1, U3.27 (IO47)
RST: U3.37 (IO41), U6.7 (/HOLDor/RESET(IO3))
SCK: U1.18 (SCK), U3.22 (IO18)
SCL: R7.2, U3.25 (IO21), U4.5 (SCL)
SDA: R8.1, U3.26 (IO26), U4.6 (SDA)
SW1: SW6.1, U3.11 (IO7)
SW2: SW7.1, U3.12 (IO8)
SW3: SW8.1, U3.13 (IO9)
SW4: SW9.1, U3.14 (IO10)
SW5: SW10.1, U3.15 (IO11)
SX_RESET: U1.15 (~RESET), U3.19 (IO15)
SYS: C28.1, C29.1, C31.2, L9.2, U4.15 (SYS), U4.16 (SYS), U5.4 (VIN), U5.5 (EN)
S_SCK: J2.2, U3.41 (IO45)
S_SDA: J2.1, U3.38 (IO42)
S_mosfet: R22.1, U3.44 (IO46)
T_INT: R27.1, U3.29 (IO34), U8.4 (~INT)
T_SCL: R26.1, U3.32 (IO36), U8.7 (SCL)
T_SDA: R25.1, U3.31 (IO35), U8.6 (SDA)
VBUS: C19.2, C32.2, U4.1 (VBUS), USB1.A4 (VBUS), USB1.A9 (VBUS), USB1.B4 (VBUS), USB1.B9 (VBUS)

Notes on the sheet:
Power managment
Step up/Step down buck
Time
Storage
Controls
ESP32
RF + antenna
USB-C
Screen

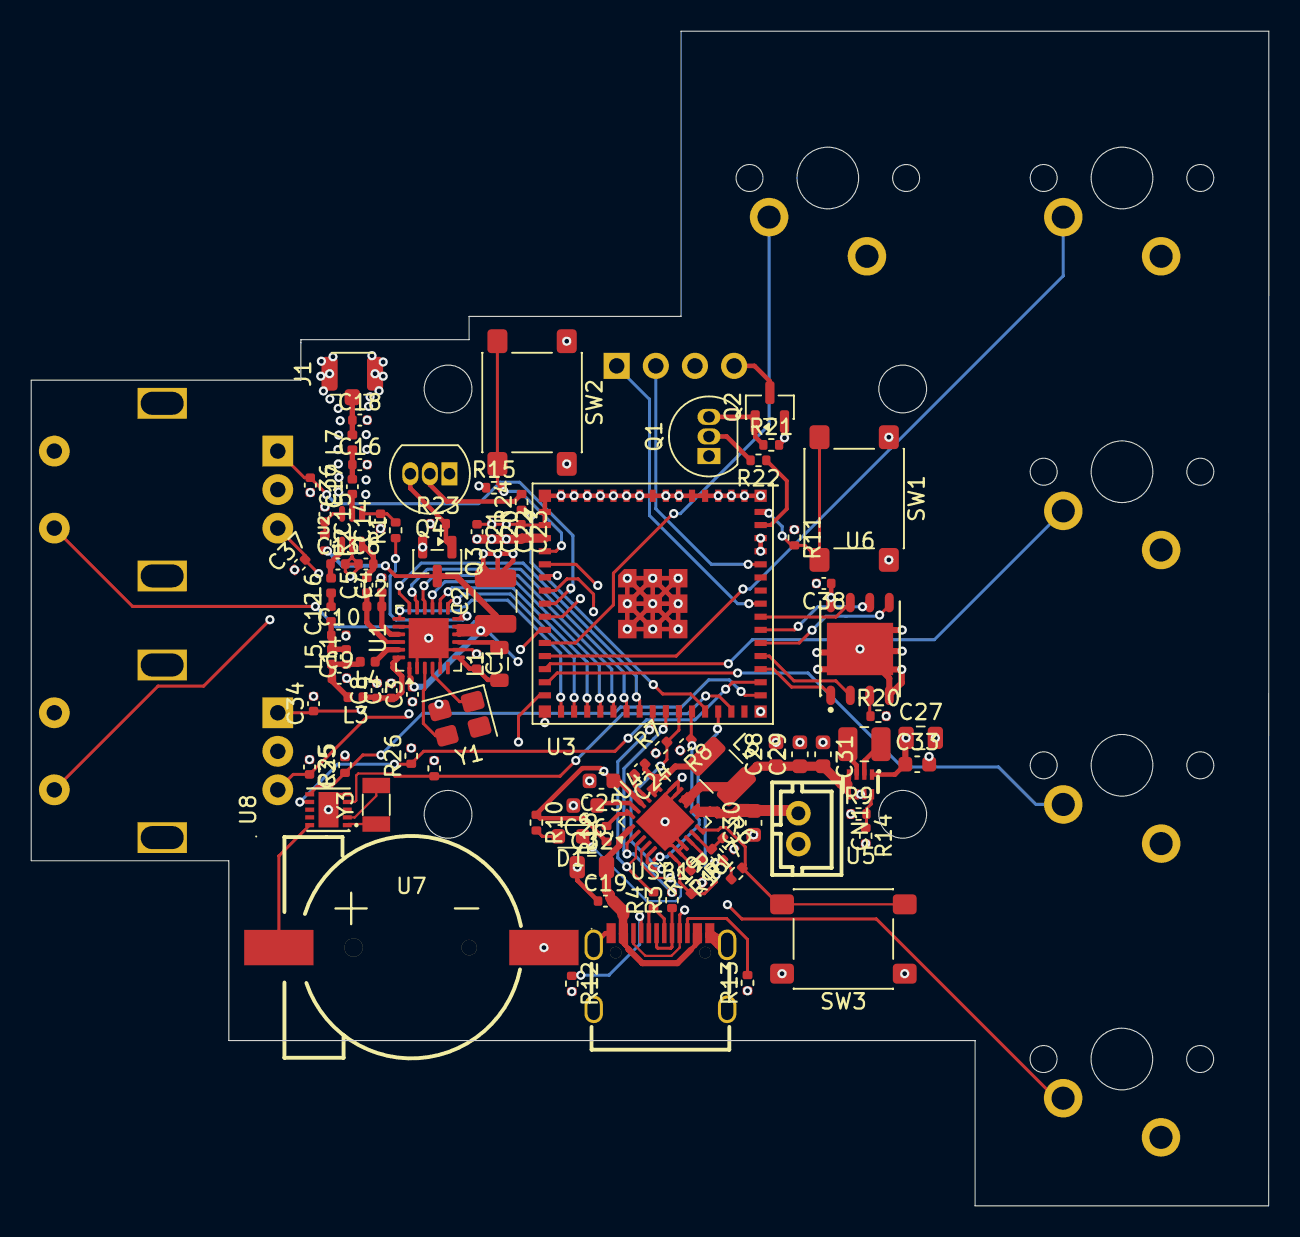
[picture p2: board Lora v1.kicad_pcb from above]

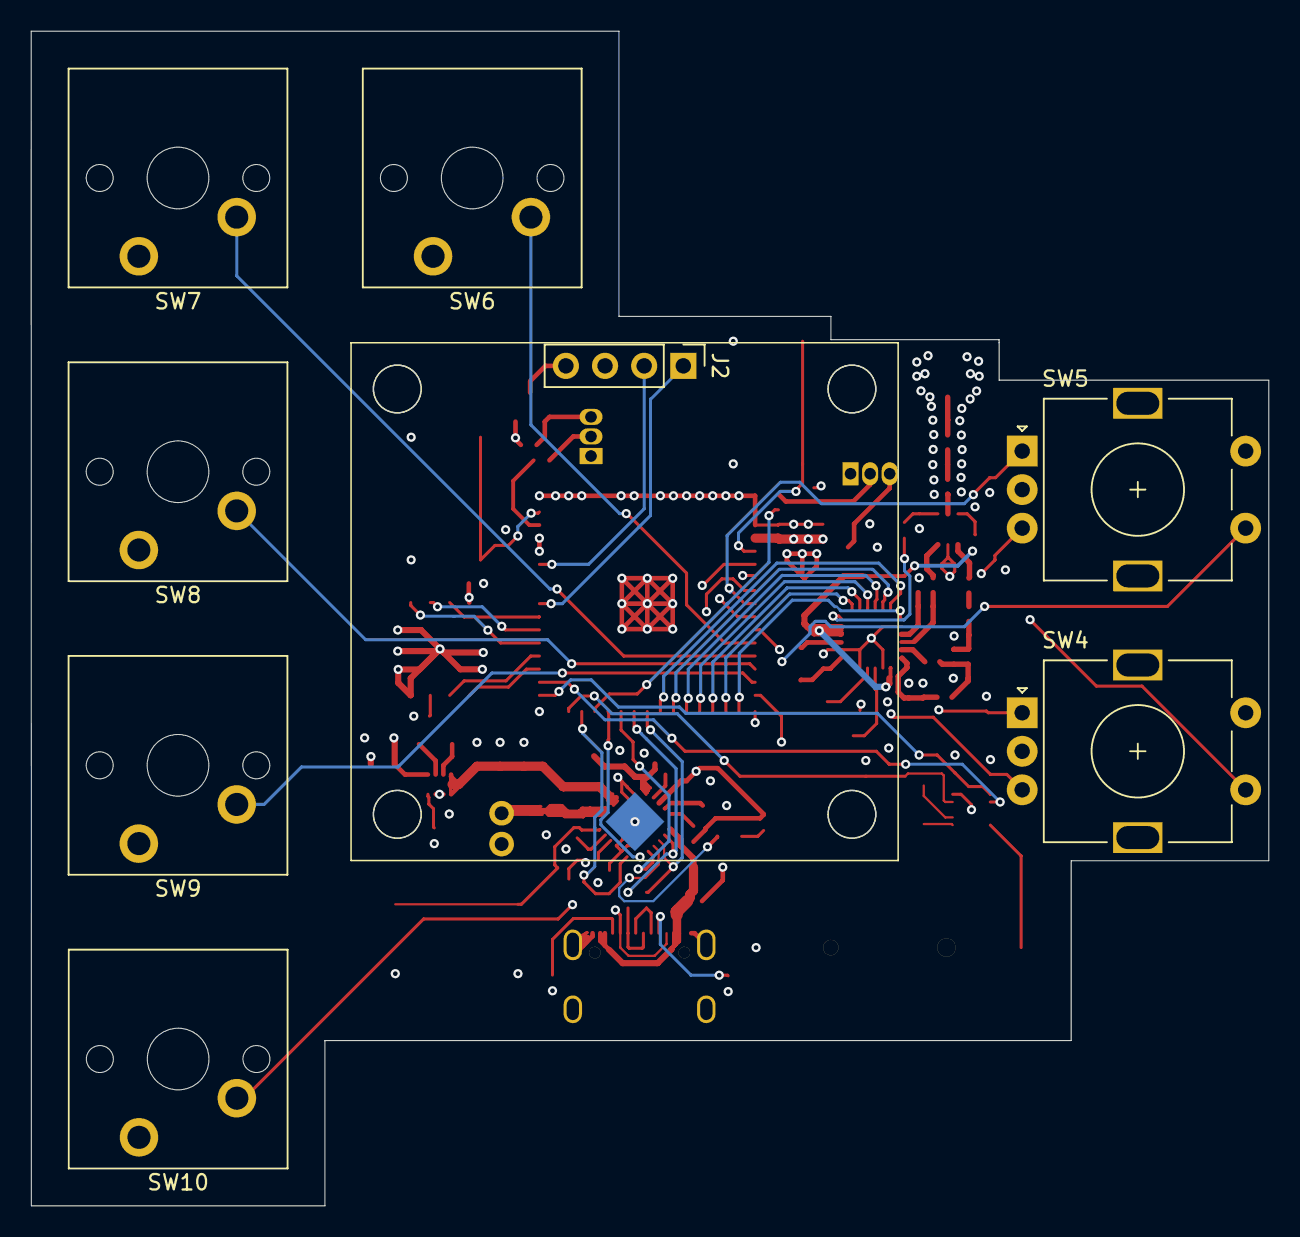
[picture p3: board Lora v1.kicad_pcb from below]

Board: 4 copper layers, 80.3 x 76.2 mm, 103 parts (8 on the bottom side), 88 nets.
